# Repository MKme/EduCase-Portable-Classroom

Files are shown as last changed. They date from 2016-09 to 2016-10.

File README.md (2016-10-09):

The EduCase is a fully functional classroom inside a portable case. 
It contains fully functional computers (Raspberry Pi) loaded with content, tuorials, tools 
and information which educators can use in any area of the world. 

<p align="center">
  
</p>

<p align="center">
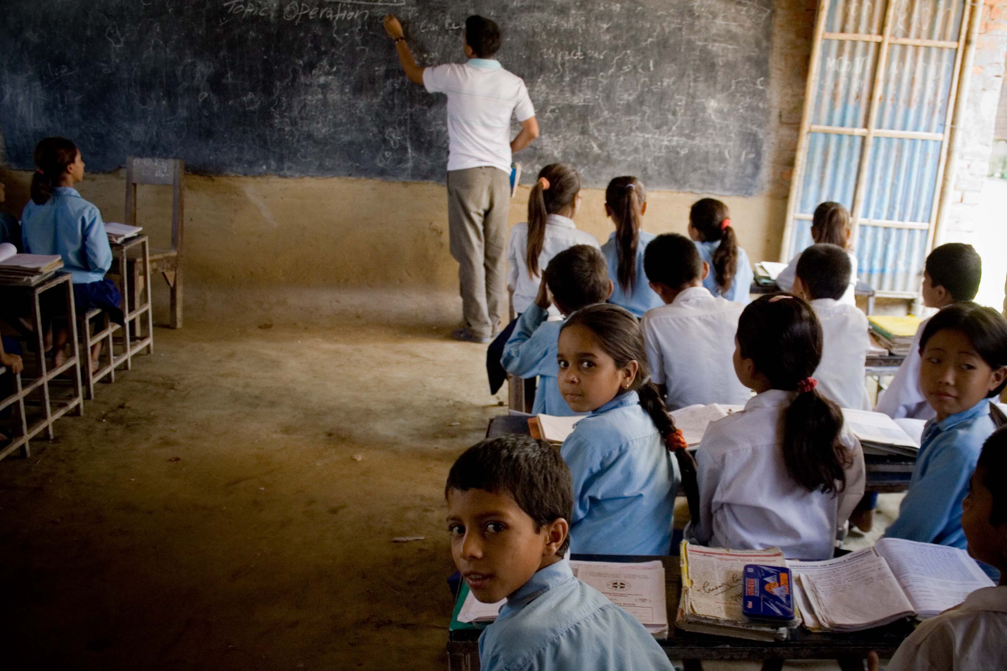
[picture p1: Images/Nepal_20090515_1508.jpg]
  
</p>
The project is fully self contained and self-powered and also includes provisions for communication 
with the outside world using either cellular data or a dedicated portable satellite dish and receiver 
linked to the Outernet. 

The case houses it's own LCD display but also utilizes an LED projector enabling the entire 
classroom to take part in any content.

<p align="center">
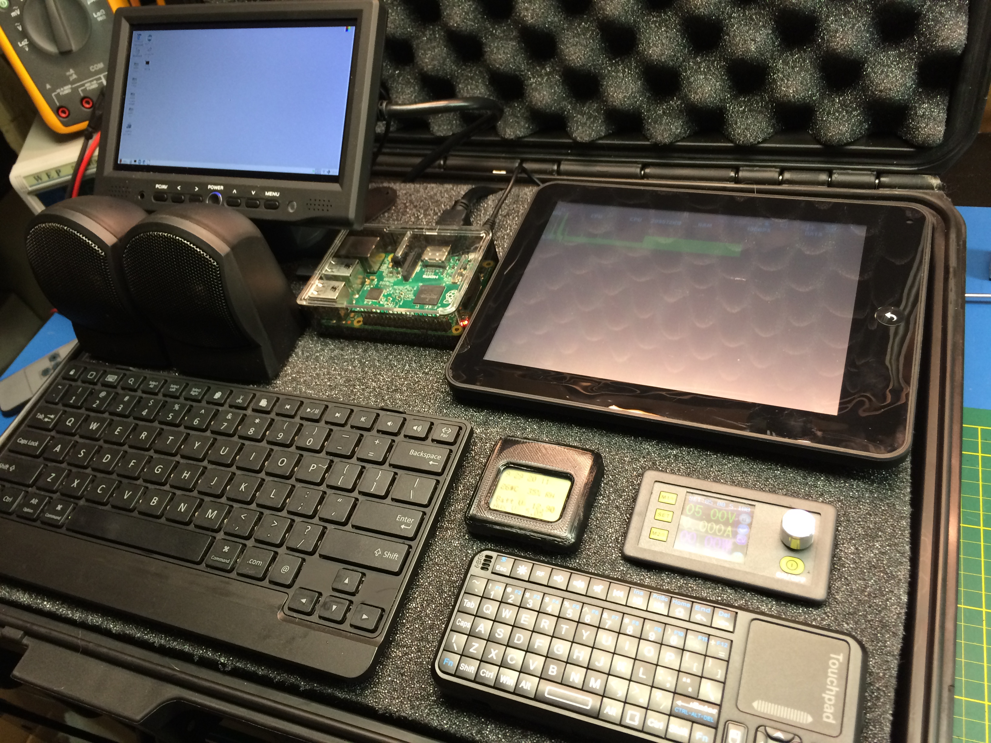
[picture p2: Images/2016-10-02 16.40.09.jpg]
  
</p>

Internal monitoring and control now provided via an Arduino Running the Aurora V1.2 Firmware. This code is 
Fully open-source and free for all to use and modify.
<p align="center">
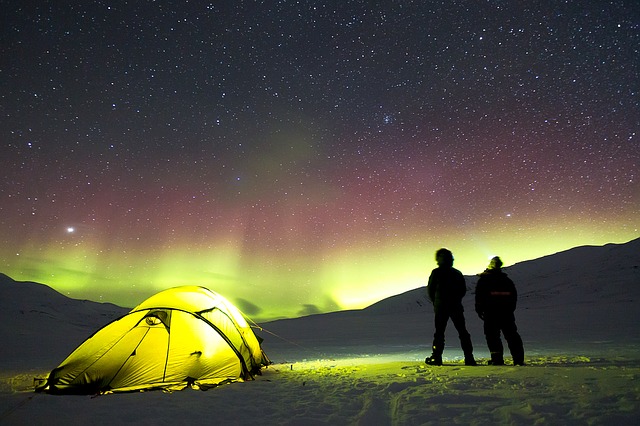
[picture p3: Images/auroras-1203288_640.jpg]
  
</p>

Project documented on Hackaday Here:
https://hackaday.io/project/11010-educase-portable-classroom

<p align="center">
  
</p>

See more of our open source projects at http://www.mkme.org  We try to share as many projects as possible which might someday
make the world a better place.

Cheers
Eric

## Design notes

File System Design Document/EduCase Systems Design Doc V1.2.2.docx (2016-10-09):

# System Design Document

# V1.2.2

Overview

The EduCase is a fully functional classroom inside a portable case. It contains multiple computers (Raspberry Pi & Android) loaded with content, tutorials, tools and information which educators can use in any area of the world.

The project is fully self-contained and self-powered and also includes provisions for communication with the outside world using either cellular data or a dedicated portable satellite dish and receiver linked to the "Outernet" satellite data provider. It also houses it's own LCD display and utilizes an LED projector enabling the entire classroom to see the content.

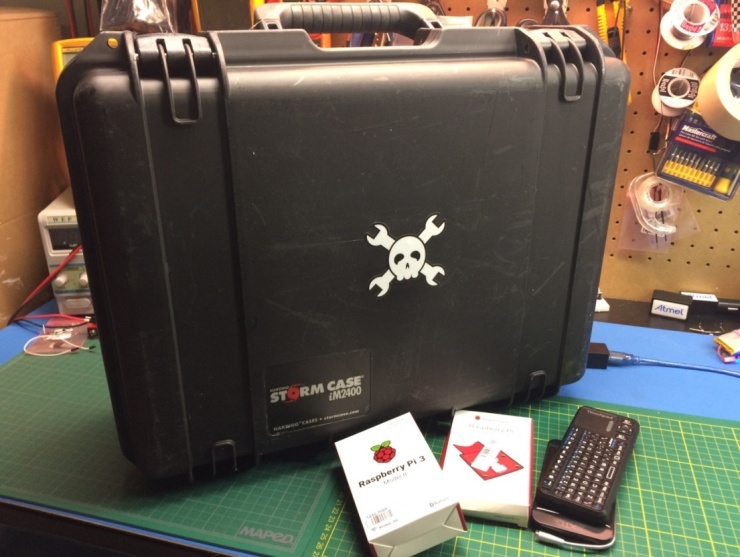
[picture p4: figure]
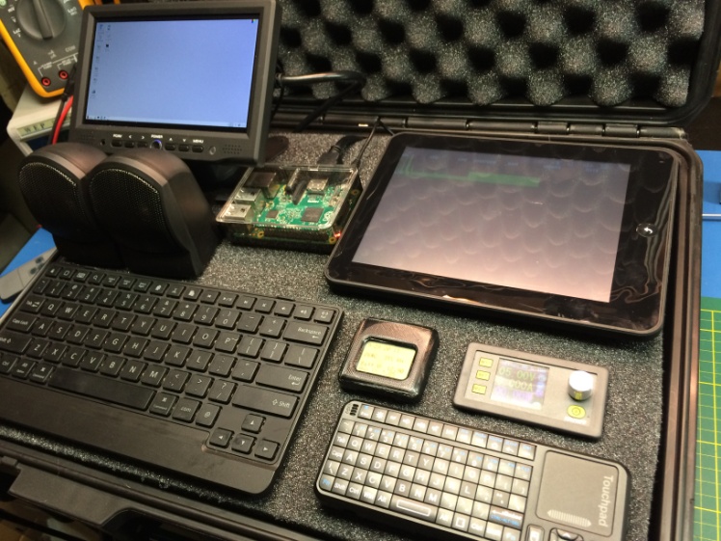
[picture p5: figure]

The EduCase can be deployed to refugee camps, rural areas, developing nations or anywhere else around the world and used to provide content, communications, courses and material we take for granted in the western world.

The EduCase can also be deployed into disaster/relief zones and used for sharing news, communication or things as simple as an impromptu movie theater.

# 1 INTRODUCTION

## 1.1 Purpose and Scope

This document is a work in progress and will be updated OFTEN. Thanks for your understanding!

The EduCase will be able to deploy technical training, medical knowledge, communication, news, and contentfrom all fields into any area of the world regardless of infrastructure.

## 1.2 Project Executive Summary

The project is open to all user modification and improvements. At its core the Raspberry Pi computer(s) provide the content and computer power needed to share information via the on board screen and projector.

This can be extremely useful for aid workers, teachers, refugee camp employees and many more.

### 1.2.1 System Overview

The Raspberry Pi computers are used to store the information, lessons and content. This can interface with the optional "Outernet" satellite downlink system or via cellualr data by tethering to the Android phone.

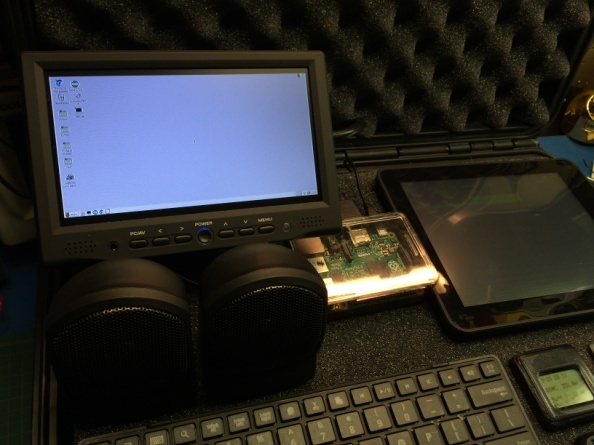
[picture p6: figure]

On board batteries supply power which can be replenished via mains power, solar panel, automotive power, generator or any other suitable source.

On board LCD display can be used for single users or deploy the included LED projector for displaying on any flat surface in order to share with a group.

Parts Video:

https://youtu.be/J0L335KiNEU

### 1.2.2 Design Constraints

Space in the case is limited so care had to be taken to include as many peripherals as possible without exceeding the volume available.

On board battery supply is limited to conserve weight but can easily be expanded if the situation requires. Lead acid batteries can also be substituted for LiPo units to reduce weight by capacity ratio.

Rasbian Image License: Debian Free Software Guidelines (https://en.wikipedia.org/wiki/Debian_Free_Software_Guidelines) (DFSG)

### 1.2.3 Future Contingencies

Expansion to control systems may require further modification. This document and files will be updated via GitHub to retain version control.

## 1.3 Document Organization

Basic explanations with expansion into subsystems as necessary.

## 1.4 Points of Contact

Support provided via the forum at http://mkme.org as well as the GIT repository.

https://github.com/MKme/EduCase-Portable-Classroom

Support for the libraries used to support the code is provided by the original authors only. Restrictions for use can be found on their respective support pages (linked within the Arduino Source Code and Raspberry Pi Files)

Forum Thread:

http://mkme.org/forum/viewtopic.php?f=32&t=702

## 1.5 Project References

Initial design completed spring 2016. Testing and updates ongoing via Hackaday website:

https://hackaday.io/project/11010-educase-portable-classroom

## 1.6 Glossary

Arduino-Arduino is an open-source computer hardware and software company, project and user community that designs and manufactures microcontroller-based kits for building digital devices and interactive objects that can sense and control the physical world.

The project is based on a family of microcontroller board designs manufactured primarily by SmartProjects in Italy, and also by several other vendors, using various 8-bit Atmel AVR microcontrollers or 32-bit Atmel ARM processors. These systems provide sets of digital and analog I/O pins that can be interfaced to various expansion boards ("shields") and other circuits. The boards feature serial communications interfaces, including USB on some models, for loading programs from personal computers. For programming the microcontrollers, the Arduino platform provides an integrated development environment (IDE) based on the Processing project, which includes support for C,C++ and Java programming languages.

# 1 SYSTEM ARCHITECTURE

Raspberry Pi Rasbian image provides basic operating system

## 1.1 Control System Architecture (Aurora Firmware)

For control and monitoring of the battery system there is an optional microcontroller control and supervision module. This consists of the Arduino Nano, temperature sensor, Real Time Clock and voltage monitoring.

The firmware (Arduino code) running on the controller is now merged into Aurora and found on GitHub

Aurora V1.2

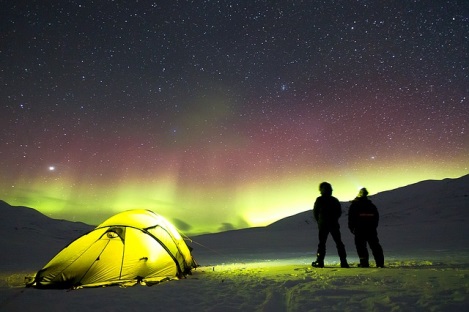
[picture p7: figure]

## 1.2 Internal Communications Architecture

Raspberry Pi wifi can be tethered to either the Lighthouse wifi hotspot or to the cellular network via the Android phone

# 2 FILE AND DATABASE DESIGN

All files and updates via GitHub:

https://github.com/MKme/EduCase-Portable-Classroom

## 2.1 System Files

- Raspberry Pi running the Raspbian operating system. Android phone and MK809 running Android OS with automatic updates.

## 2.2 Non- System Files

- Remote updates and file downloads from the Outernet interface as well as standard data delivery over cellular data.

# 3 HUMAN-MACHINE INTERFACE

1. LCD Monitor
2. LED Pico Projector
3. Android Phone Display
4. Battery Monitoring Display (Nokia 5110 LCD)

## 3.1 Inputs

- Wireless Keyboard
- Bluethooth Keyboard
- Wireless Mouse
- Touch pads on Tablet PC & Cellular Phone

## 3.2 Outputs

- HDMI video
- Stereo Audio
- Wireless LAN
- Bluetooth Data

# 4 DETAILED DESIGN

## 4.1 High Level Schematic Diagram

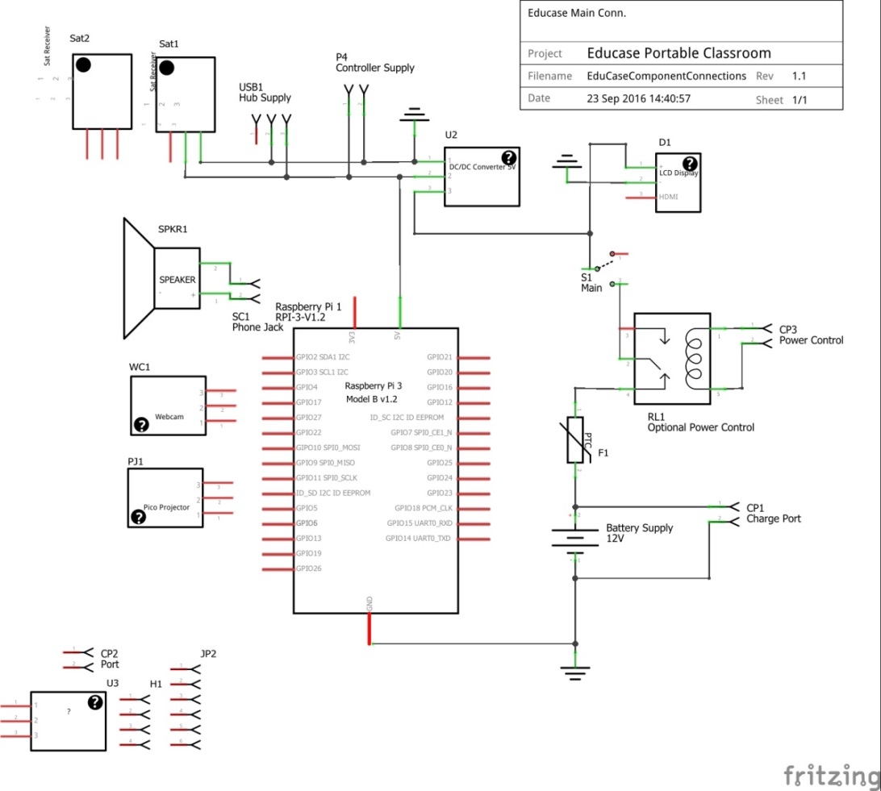
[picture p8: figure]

## 4.2 Software Detailed Design

Software design for all programs used is beyond the scope of this document. Software logic for the monitoring and control systems can be summarized in the blow functional flow.

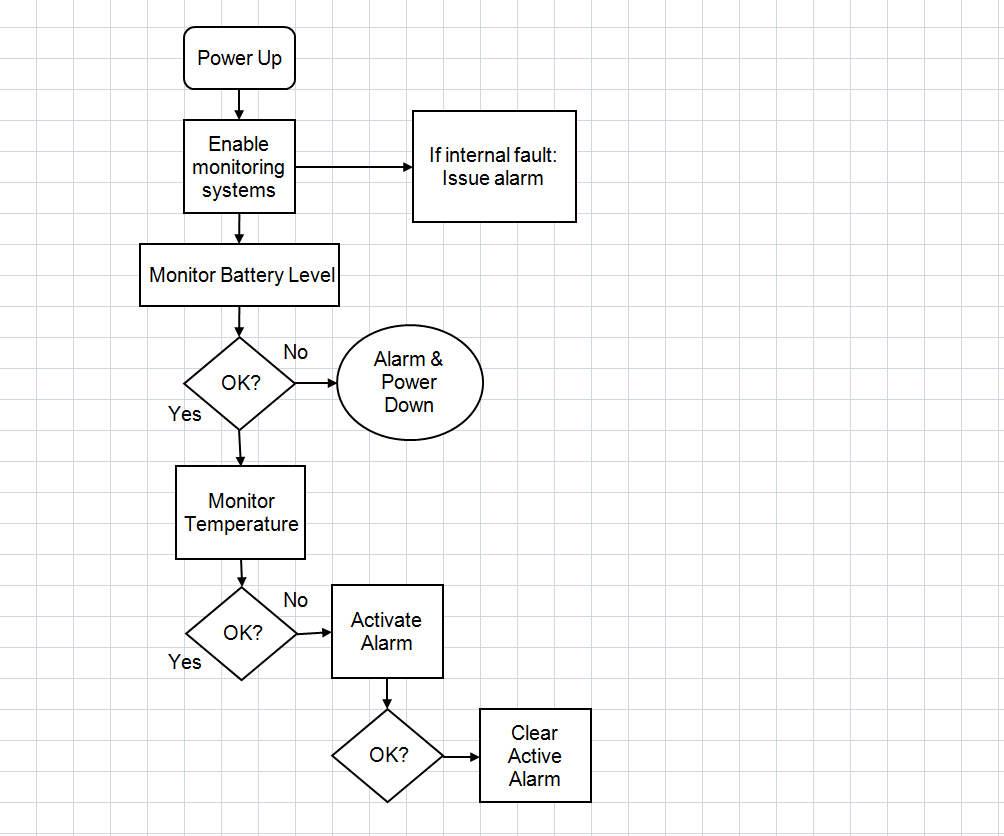
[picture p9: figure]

Functional description of the control logic:

Alarm indications are provided to the user via the LCD display. The backlight for the display flashes at 1hz while AlarmActive==True. Future models will incorporate audible notification as well.

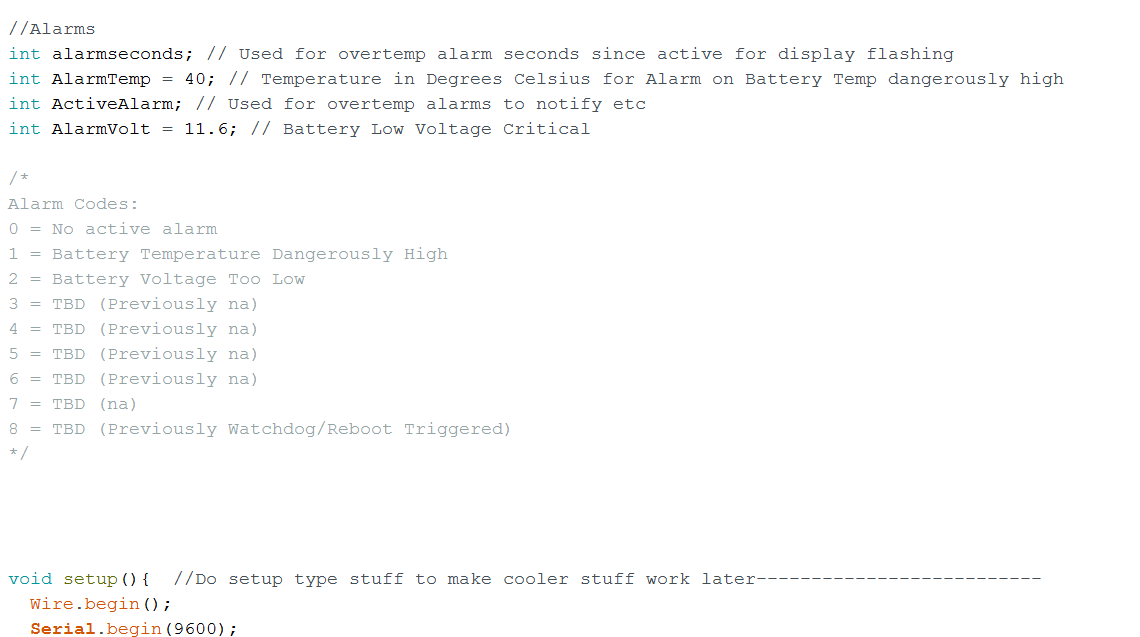
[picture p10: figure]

Much of the details can be found in the Arduino code itself (Aurora V1.2)

Example Alarm Info:

## 4.3 Internal Communications Detailed Design

- Wireless networking via 2.4 ghz utilized for file transfer between systems
- I2C communication utilized for Real Time Clock
- SPI utilized for remaining components

# 5 EXTERNAL INTERFACES

- Cellular Mobile data
- Outernet satellite receiver system

## 5.1 Control Board Design

Full Gerber files provided via GitHub Repository. These files are provided open source to anyone. These files will be updated in the upcoming months to include better trace routing and provisions for more dedicated ports (buzzer, etc)

Top:

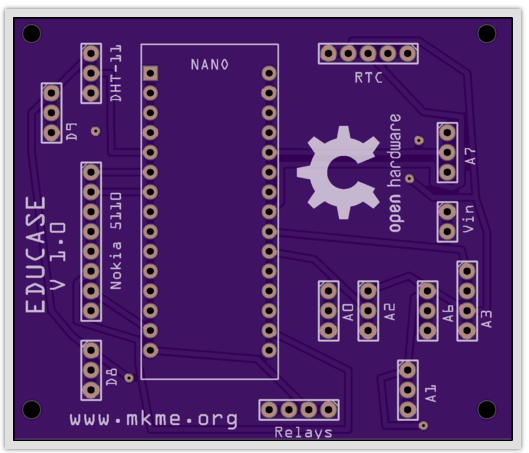
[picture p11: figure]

Bottom:

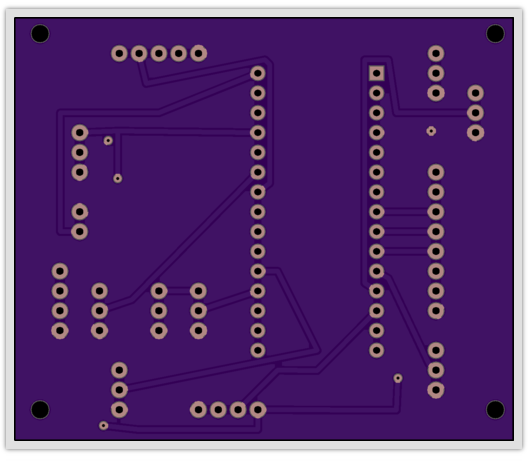
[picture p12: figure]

Educase portable classroom www.mkme.org

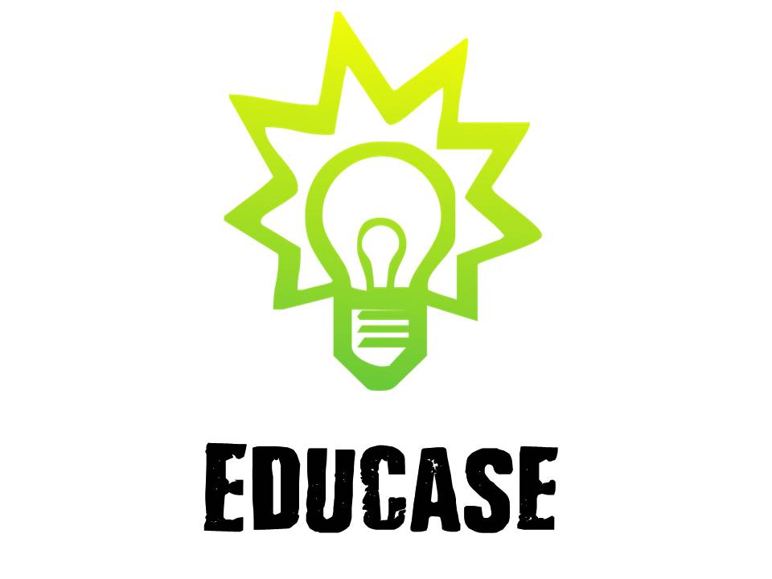
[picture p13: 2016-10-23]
Images/EduCase Pi Wallpaper.jpg

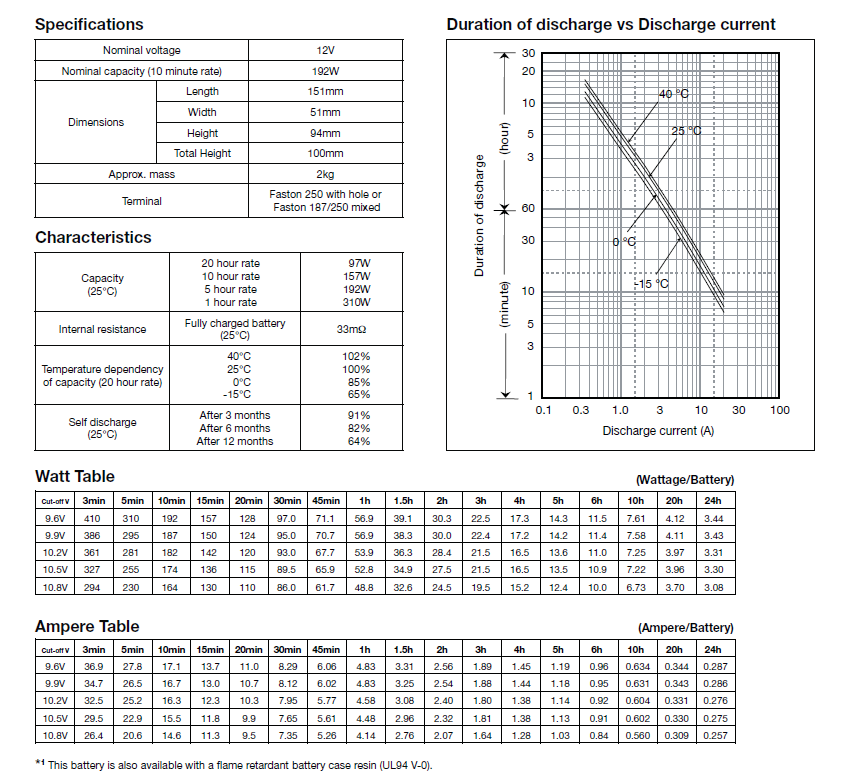
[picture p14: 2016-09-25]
Images/BatterySpecs.PNG

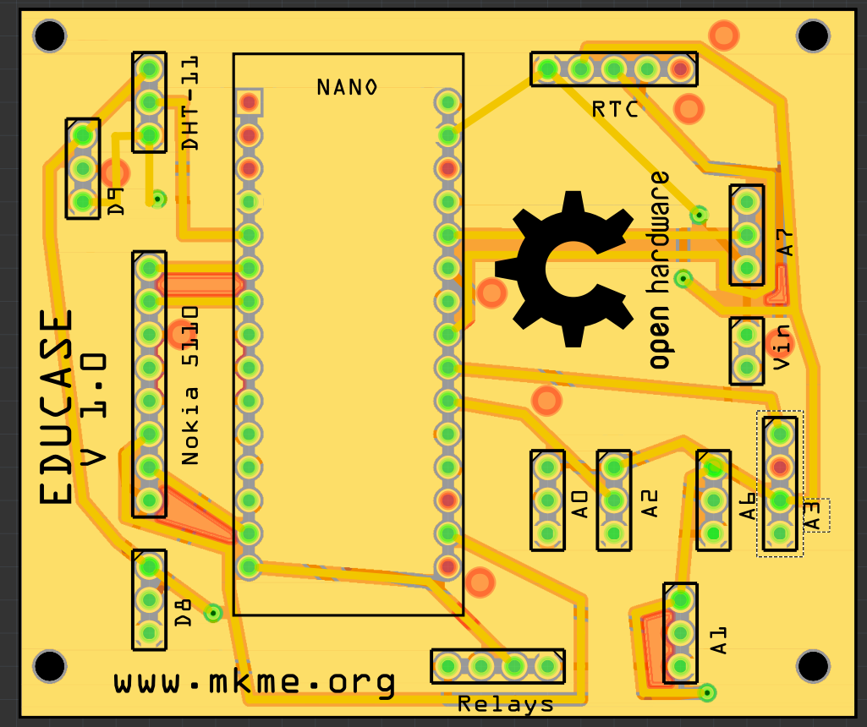
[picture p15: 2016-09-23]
Controller PCB and Schematics/Board Layout .PNG

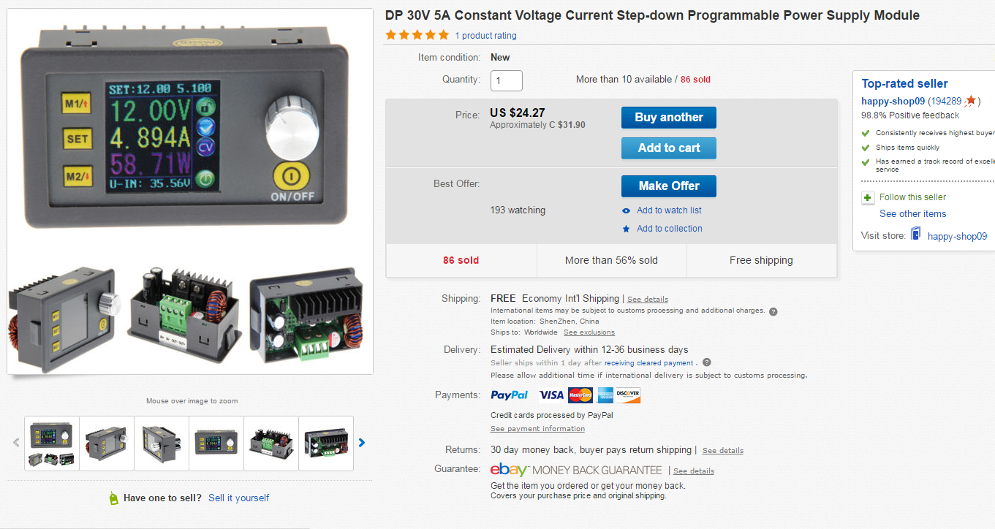
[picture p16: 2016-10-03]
Images/ElectyronicsLab Power Supply.PNG

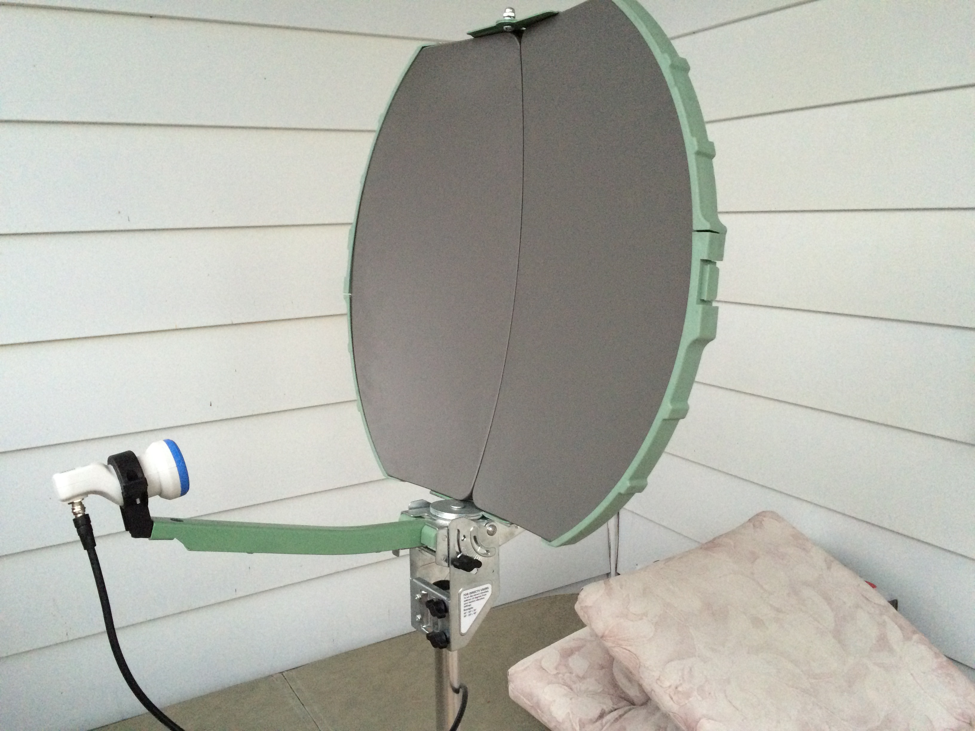
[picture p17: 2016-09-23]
Images/2015-12-30 16.21.28-1.jpg

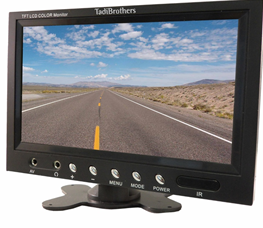
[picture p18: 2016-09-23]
Images/monitor.PNG

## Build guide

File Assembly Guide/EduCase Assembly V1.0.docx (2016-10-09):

# V1.0- Initial commit

# V1.1- Updated Parts/Links

# V1.1- Complete overhaul

Assembly Guide Overview

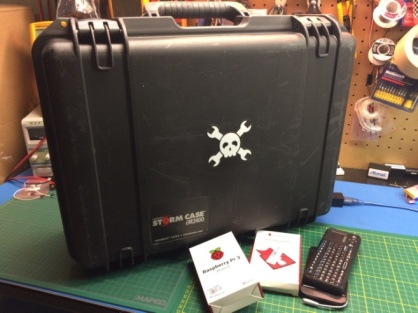
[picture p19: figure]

The EduCase is a fully functional classroom inside a portable case. It contains multiple computers (Raspberry Pi & Android) loaded with content, tutorials, tools and information which educators can use in any area of the world.

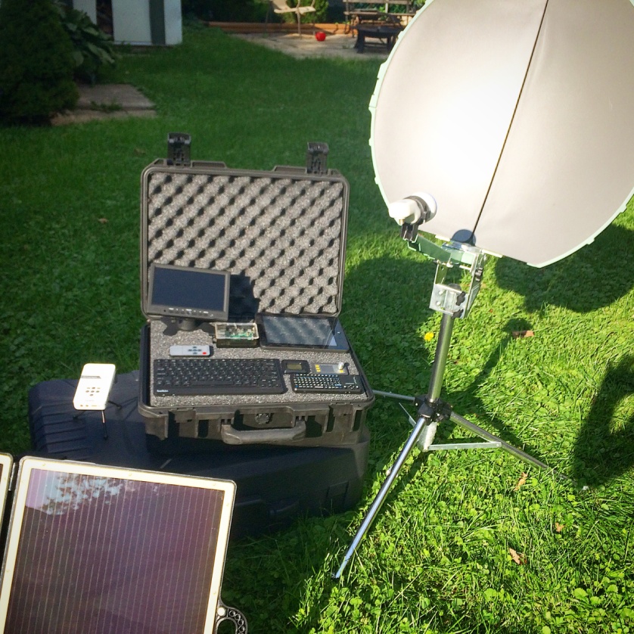
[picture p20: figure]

The project is fully self-contained and self-powered and also includes provisions for communication with the outside world using either cellular data or a dedicated portable satellite dish and receiver linked to the "Outernet" satellite data provider.

It also houses its own LCD display and utilizes an LED projector enabling the entire classroom to see the content.

The EduCase can be deployed to refugee camps, rural areas, developing nations or anywhere else around the world and used to provide content, communications, courses and material we take for granted in the western world.

The EduCase can also be deployed into disaster/relief zones and used for sharing news, communication or things as simple as an impromptu movie theater.

# 1 INTRODUCTION

## 1.1 Basics

This document is a work in progress and will be updated OFTEN. Thanks for your understanding!

The EduCase will be able to deploy technical training, medical knowledge, communication, news, and contentfrom all fields into any area of the world regardless of infrastructure.

## 1.2 References

Parts Video: https://youtu.be/J0L335KiNEU

Contact

Support provided via the forum at http://mkme.org as well as the GIT repository.

Support for the libraries used to support the code is provided by the original authors only. Restrictions for use can be found on their respective support pages (linked within the Arduino Source Code and Raspberry Pi Files)

Forum Thread:

http://mkme.org/forum/viewtopic.php?f=32&t=702

# All files and source code:

All files and updates via GitHub:

https://github.com/MKme/EduCase-Portable-Classroom

## 1.3 Project References

Initial design completed spring 2016. Testing and updates ongoing via Hackaday website:

https://hackaday.io/project/11010-educase-portable-classroom

## 1.4 Assembly

1. Gather the required components for assembly into your case. Pelican style cases are preferred due to the depth and resistance to water intrusion. You can find many options here: http://www.pelicancases.com/

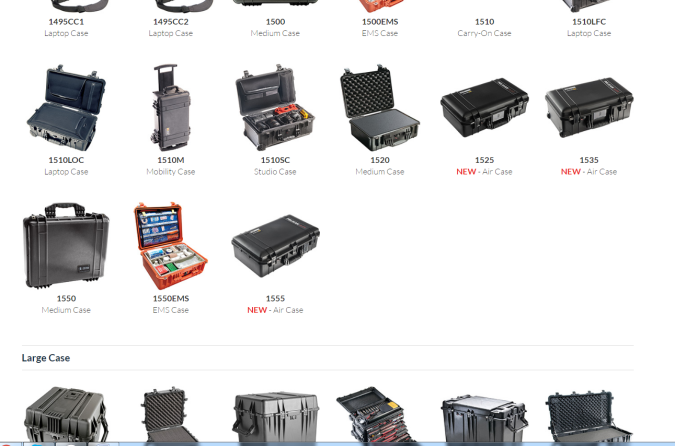
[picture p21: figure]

I made a sort parts overview video you can see here: https://www.youtube.com/watch?v=J0L335KiNEU

2. Assemble the batteries into the case as per the electrical schematic found on GitHub.

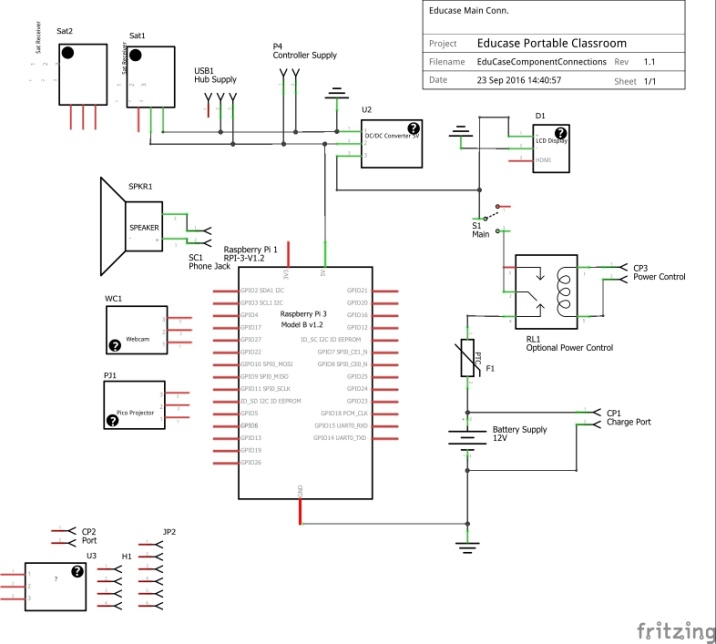
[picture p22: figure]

You can use any time of battery you wish but it is preferable to use lead acid batteries which lend themselves better to these discharge cycles better than LiPo etc.

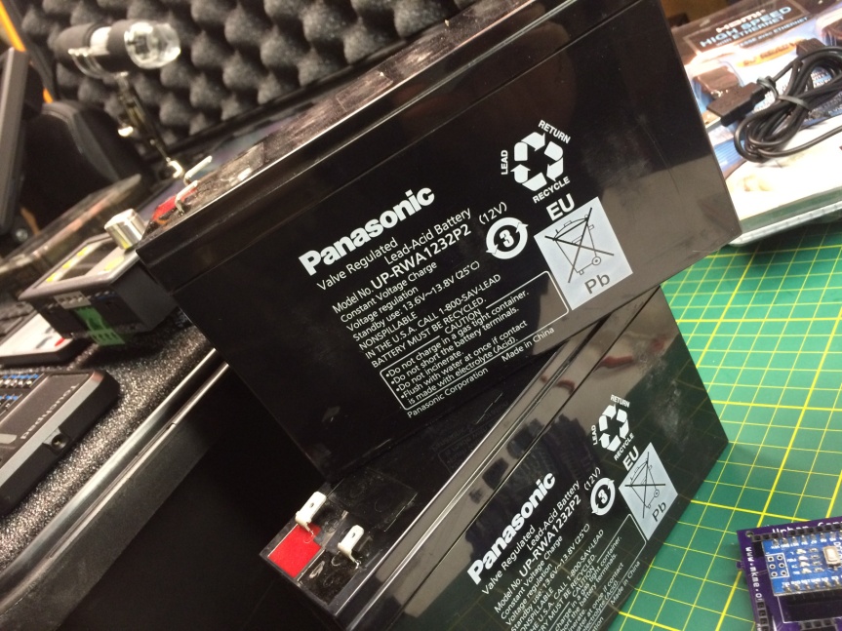
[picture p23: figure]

Ensure you fuse the battery output as per the schematic using protection of your choice. A PTC is preferable but and automotive spade-style fuse can also be used and are easily available from many sources

3. At this time it is best to decide if you will incorporate the Arduino controller into the case.

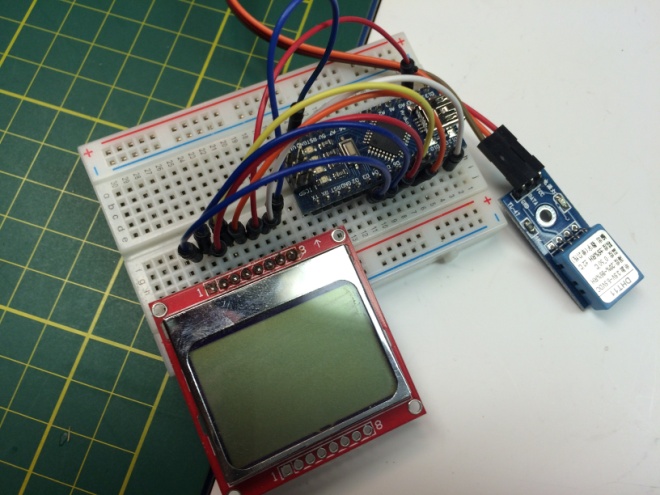
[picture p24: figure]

It will be easier to wire the relay power control and temperature sensor now before you finalize the component locations inside the case. If you choose to use the control you can order the printed circuit board using the files I have provided on GitHub. Wire the components as per the layout in the code and schematics and flash the Arduino with the code provided.

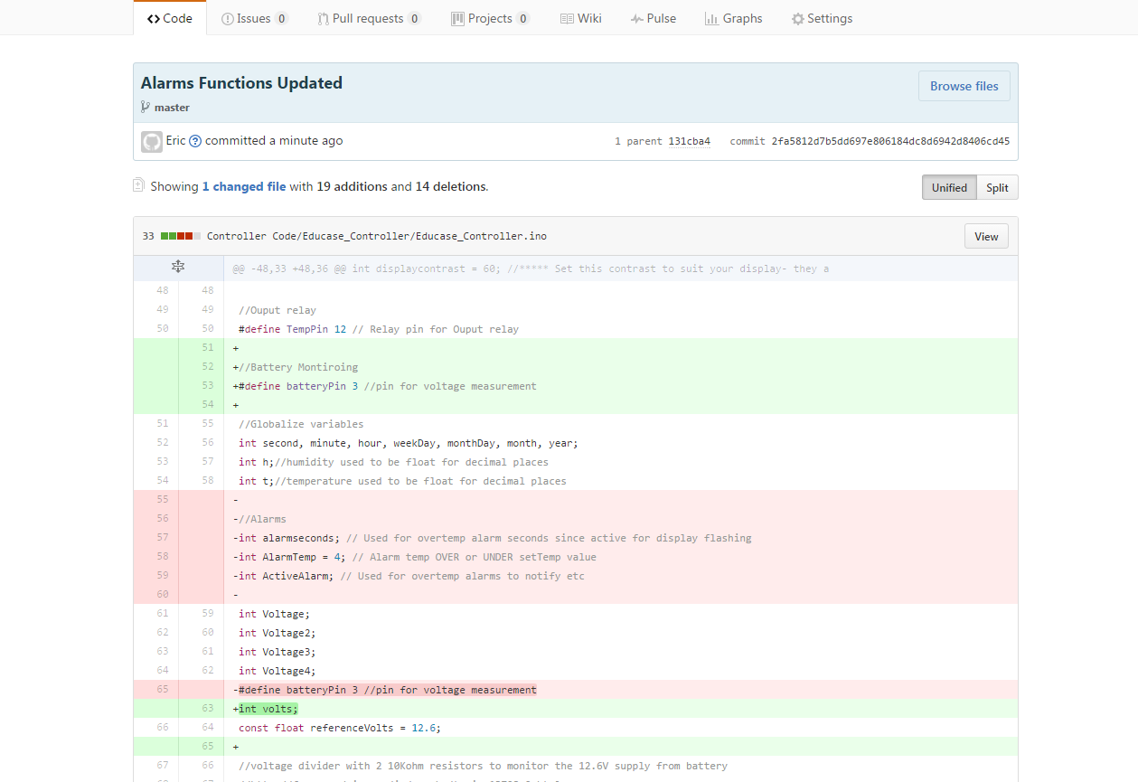
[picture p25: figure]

Download the Aurora firmware from Github and flash using the Arduino IDE from https://www.arduino.cc/en/Main/Software

4. If you implement the controller you may wish to mount your Nokia 5110 LCD permanently in the case. Within the files on Github there is a folder for CAD files and documents. Within it you will find a stylish bezel for the LCD. You can 3D print this yourself or use and online source such as Shapeways.

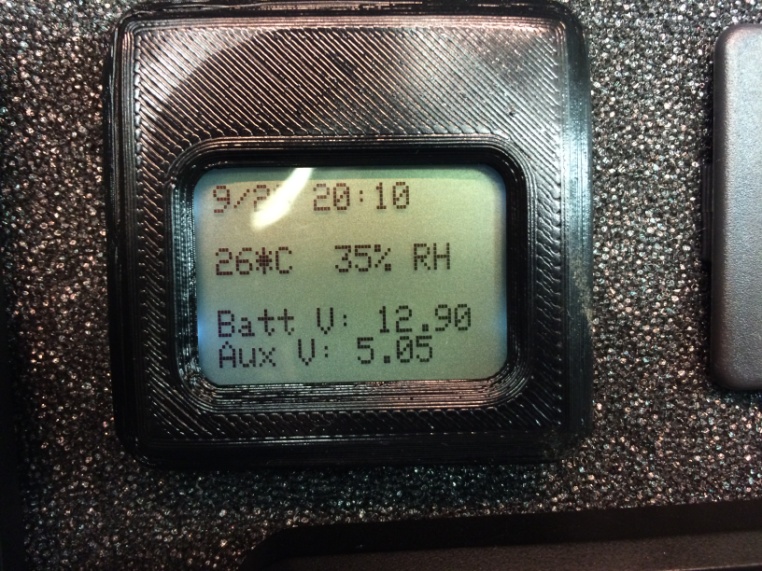
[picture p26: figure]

5. Customize the code as you wish to include time, temperature and voltage alarms and control. If you make changes please consider sharing them back with the world open-source.


6. Lay out the components inside your case as per your hardware. You can use the foam inserts and carve them out to snugly fit your monitor, Raspberry Pi and still leave room for storage of components and equipment such as webcams, remotes etc

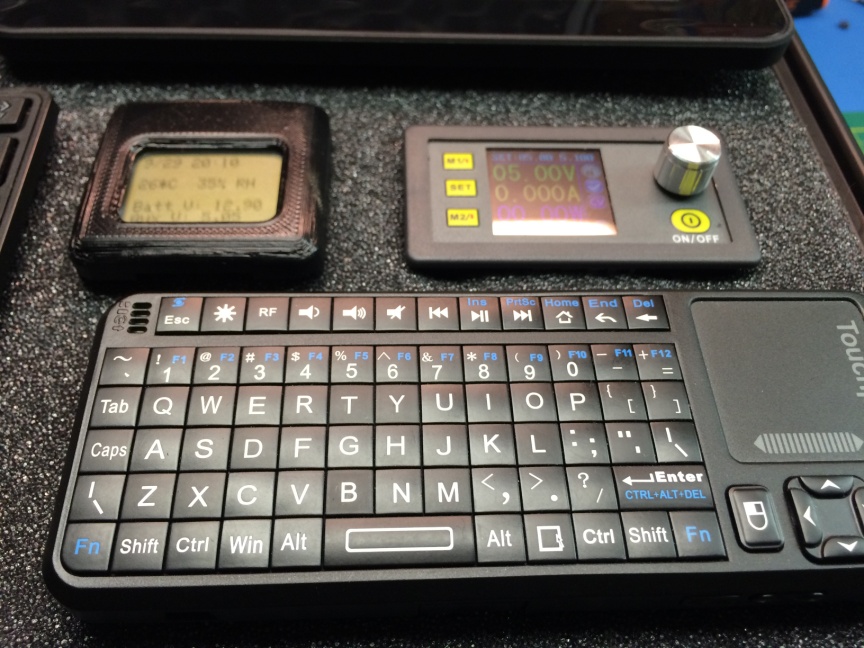
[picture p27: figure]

Route the USB wiring, video and audio cables to suit your installation. I suggest leaving extra HDMI cable easily accessible so the projector and monitor can be used outside the case. This makes presenting to a classroom environment much easier as you can place the case away from your work/presentation area.

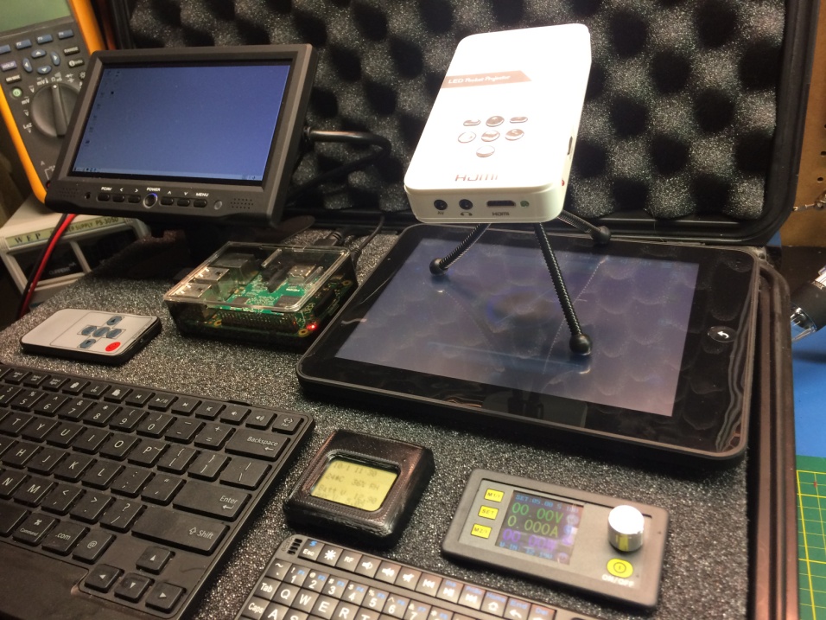
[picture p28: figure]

7. Add a powered USB hub with the number of ports needed for your particular project. I suggest at least 10. The power for the hub is supplied via the DC/DC converter as per the schematic.

These units can be found as “buck converters” from any electronics source. Some suggested versions are given in the parts list in this project.

Mount the hub so it is convenient to access at least a few ports during normal use for plugging in items for charging, webcams etc.

8. Install the Raspbian operating system on your Raspberry Pi. I have made a video detailing this here:https://www.youtube.com/watch?v=29ejr-KFxvY

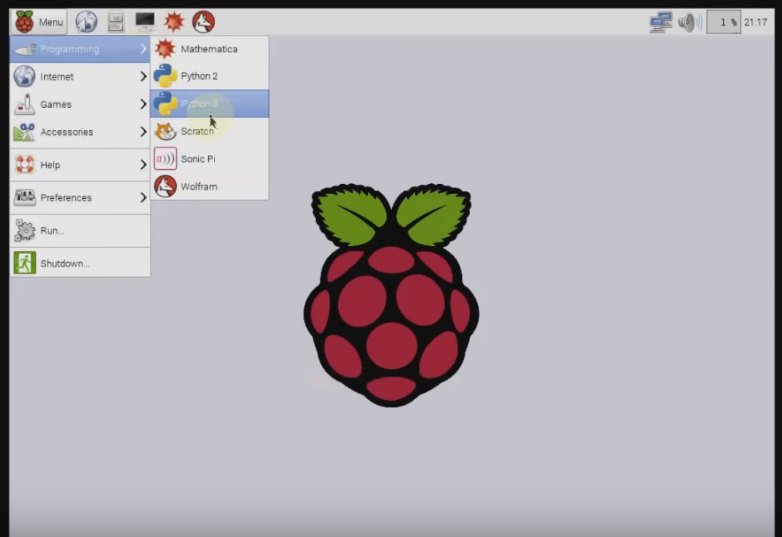
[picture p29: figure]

9. You will want to be installing many files and learning content on the Pi so installing a remote VNC connection will make this much easier. Install remote desktop connection as per the video I made here:

https://www.youtube.com/watch?v=P5lPmXTgwu0

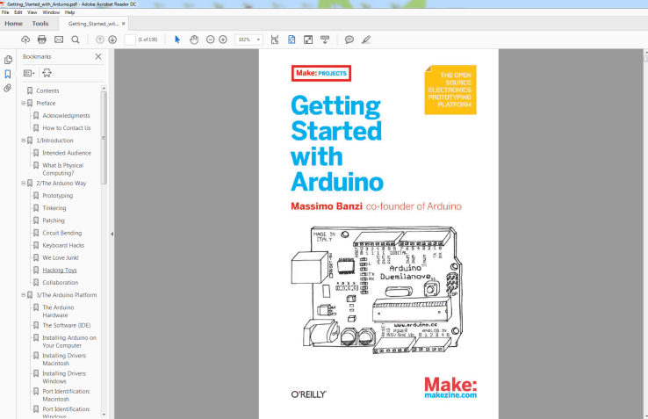
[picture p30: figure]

10. Copy all the files and content over to your Raspberry Pi. I also place some of the media files on the Android phone. It hooked up to the projector does a much better job at media file playback such as video/movies. I cannot provide the files I am using due to copyright etc so please don’t ask for them. Sorry.
11. If you are also constructing the portable satellite dish you will need to swap out the LNB that comes with the dish to a Linear LNB. They can be sourced easily on eBay or Amazon. Install the LNB in the same position as the original. The distance from the face of the LNB to the dish itself must remain the exact same to retain the correct focus.This can be done with a simple measuring tape.

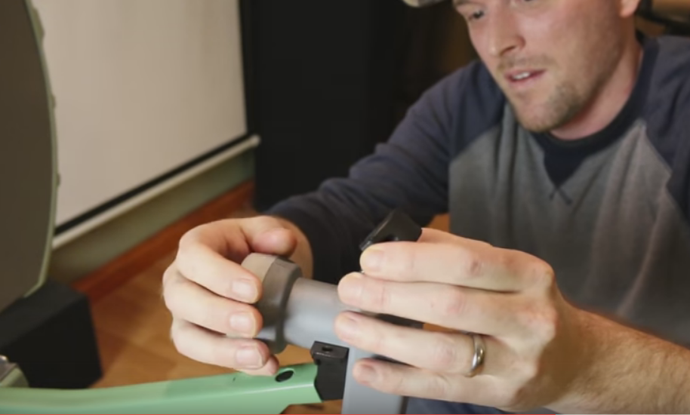
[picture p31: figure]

## 1.5 Glossary

Arduino- Arduino is an open-source computer hardware and software company, project and user community that designs and manufactures microcontroller-based kits for building digital devices and interactive objects that can sense and control the physical world.

The project is based on a family of microcontroller board designs manufactured primarily by SmartProjects in Italy, and also by several other vendors, using various 8-bit Atmel AVR microcontrollers or 32-bit Atmel ARM processors. These systems provide sets of digital and analog I/O pins that can be interfaced to various expansion boards ("shields") and other circuits. The boards feature serial communications interfaces, including USB on some models, for loading programs from personal computers. For programming the microcontrollers, the Arduino platform provides an integrated development environment (IDE) based on the Processing project, which includes support for C,C++ and Java programming languages.

Educase portable classroom- Assembly Guide www.mkme.org

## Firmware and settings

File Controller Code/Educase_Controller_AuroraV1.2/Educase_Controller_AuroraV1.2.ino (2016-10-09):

/* 
Erics Open Source Educase Portable classroom
Firmware: Aurora V1.2

This code is for the Arduino monitoring and control board to prevent damage to onboard systems
Alarms displayed via LCD and power control via relay RL1
My Youtube Channel  : http://www.youtube.com/mkmeorg
If you use this code or personalize it etc- please consider sharing it back with the world Open-Source 
This sketch is currently using Arduino Nano V3.0

Get all schematics and instructions for the EduCase project on GitUHub at https://github.com/MKme/EduCase-Portable-Classroom

This code uses the fantastic Nokia 5110 library provided FREE by Adafruit Industries
If you use this for your project consider buying some of your parts from them at http://adafruit.com
Show them some love for supporting the maker movement with tonnes of free tutorials and code.

Real Time Clock (RTC) support:
 http://www.hobbyist.co.nz/?q=real_time_clock
 RTC Connected to VCC and Ground Only- Additional Vbatt and Temp to be added later
 I2C Connections:
 RTC SDA connected to pin Analog 4
 RTC SCL connected to pin Analog 5

Used I2CScanner.ino to find I2C addresses- 0x50 (EEPROM?)  and 0x68 found
Used SetRTC.ino to manually set proper date/date on RTC module- This wil set the date/time as soon as serial 
is initiated so set ahead by a minute and wait till time matches then open serial window to set.
Downloaded from http://projectsfromtech.blogspot.com/

DHT11 Temp Sensor:
Connect pin 1 (on the left) of the sensor to +5V
Connect pin 2 of the sensor to whatever your DHTPIN is
Connect pin 4 (on the right) of the sensor to GROUND
Connect a 10K resistor from pin 2 (data) to pin 1 (power) of the sensor

Pin 11 for contrast on the Nokia 5110 (see below)

*/

#include "Wire.h" //RTC
#define DS1307_ADDRESS 0x68 //For RTC Support
byte zero = 0x00; //workaround for issue #527 on RTC
#include "DHT.h"  //You need this library
#define DHTPIN 2     // DHT11 Humidity Pin
#define DHTTYPE DHT11   // DHT 11 
DHT dht(DHTPIN, DHTTYPE);//needed by DHT11
#include "Adafruit_GFX.h"  //Awesome Adafruit libraries- download from their site
#include "Adafruit_PCD8544.h"  //Awesome Adafruit libraries- download from their site
Adafruit_PCD8544 display = Adafruit_PCD8544(7, 6, 5, 4, 3);//4 and 3 are reversed on the cheap eBay models

//LCD display & backlight control 
#define backlightpin 11 //Pin for LCD backlight
int backlightlevel = 220; //Level for backlight PWM
int backlightoff = 255; //Level which turns backlight off completely
int displaycontrast = 60; //***** Set this contrast to suit your display- they are indeed different between production runs

//Ouput relay
#define LIGHTPIN 10 //Pin for output relay

//Temp Pin if used
#define TempPin 12 // Relay pin for Temp

//Battery Montitoring
#define batteryPin 3 //pin for voltage measurement

//Globalize variables
int second, minute, hour, weekDay, monthDay, month, year;
int h;//humidity used to be float for decimal places
int t;//temperature used to be float for decimal places
int Voltage;
int Voltage2;
int Voltage3;
int Voltage4;
int volts;
const float referenceVolts = 12.6;  

//voltage divider with 2 10Kohm resistors to monitor the 12.6V supply from battery
//http://forum.arduino.cc/index.php/topic,13728.0.html
//currently rersistors not included on pre-made PCB so wire externally

//Alarms
int alarmseconds; // Used for overtemp alarm seconds since active for display flashing
int AlarmTemp = 40; // Temperature in Degrees Celsius for Alarm on Battery Temp dangerously high
int ActiveAlarm; // Used for overtemp alarms to notify etc
int AlarmVolt = 11.6; // Battery Low Voltage Critical

/*
Alarm Codes:
0 = No active alarm
1 = Battery Temperature Dangerously High
2 = Battery Voltage Too Low
3 = TBD (Previously na)
4 = TBD (Previously na)
5 = TBD (Previously na)
6 = TBD (Previously na)
7 = TBD (Previously Fatal Error)
8 = TBD (Previously Watchdog/Reboot Triggered)
*/




void setup(){  //Do setup type stuff to make cooler stuff work later--------------------------
  Wire.begin();
  Serial.begin(9600);
  dht.begin();//initialize temp and humidity
  analogWrite(backlightpin,backlightlevel);// PWM of LCD backlight but ebay unit is backwards-   //must go high + cycle to dim   //Very Dim=230
  display.begin();//Display code
  display.setContrast(displaycontrast);//Nokia 5110 works best at 50- no more flicker
  delay(1000);  //party foul I know but it is only setup
  display.clearDisplay();     // clears the screen and buffer- makes gooder stuff show up later
  display.setTextSize(1);     // set text size
  display.setTextColor(BLACK);
  
 // Splash Screen - 
  display.setTextSize(1);
  display.setTextColor(BLACK);
  display.setCursor(0,0);
  display.println("  Eric's");
  display.println("");
  display.println(" Educase");
  display.println(" Portable");
  display.println(" Classroom");
  display.display();
  delay(2000);
  display.clearDisplay();     // clears the screen and buffer
  
 }

void loop(){
  TimeFunctions();   //Do the time related stuff
  TempFunctions();   //Do the temp related stuff
  VoltageFunctions();   //Do the temp related stuff
  debug();           //Figure out what has broken type of stuffs
  LCDDisplay();      //Send everything to the LCD display
  Alarm();           //Activate alarm if applicable
  DisplayFlash();    //Flash display if alarm active
  
}


//------------------------------This needed by RTC
byte decToBcd(byte val){  //Needed for RTC
// Convert normal decimal numbers to binary coded decimal
  return ( (val/10*16) + (val%10) );
}

byte bcdToDec(byte val)  {  //Needed for RTC
// Convert binary coded decimal to normal decimal numbers
  return ( (val/16*10) + (val%16) );
}
//------------------------------End needed by RTC


//Do time related stuffs so cool stuffs work gooder------------------------------
void TimeFunctions(){ 
  // Reset the register pointer
  Wire.beginTransmission(DS1307_ADDRESS);
  Wire.write(zero);
  Wire.endTransmission();
  Wire.requestFrom(DS1307_ADDRESS, 7);
  second = bcdToDec(Wire.read());
  minute = bcdToDec(Wire.read());
  hour = bcdToDec(Wire.read() & 0b111111); //24 hour time
  weekDay = bcdToDec(Wire.read()); //0-6 -> sunday - Saturday
  monthDay = bcdToDec(Wire.read());
  month = bcdToDec(Wire.read());
  year = bcdToDec(Wire.read());
}

//Do temperature related stuffs----------------------------------------------------------
void TempFunctions(){
  // Reading temperature or humidity takes about 250 milliseconds!
  // Sensor readings may also be up to 2 seconds 'old' (its a very slow sensor)
  h = dht.readHumidity();
  t = dht.readTemperature();
}

void VoltageFunctions(){
int val = analogRead(batteryPin);  // read the value from the A0 battery monitoring pin with voltage divider
//if you run in to any odd measurements here- take a second read and throw out the first- this will get rid of the known analog read bug with some chips
float volts = (val / 511.0) * referenceVolts ; // divide val by (1023/2)because the resistors divide the voltage in half
  
}
//Do debugging stuffs for nerds only-----------------------------------------------------------------
void debug(){  //This area only used for debugging any changes to the code- handy dandy sometimes :)
  if (Serial.available()){ //Can leave debug active as no resources used when not connected
  //Date and Time Values   3/1/11 23:59:59
  Serial.print(month);
  Serial.print("/");
  Serial.print(monthDay);
  Serial.print("/");
  Serial.print(year);
  Serial.print(" ");
  if (hour < 10) Serial.print("0");
  Serial.print(hour);
  Serial.print(":");
  if (minute < 10) Serial.print("0");
  Serial.print(minute);
  Serial.print(":");
  if (second < 10) Serial.print("0");
  Serial.println(second);
    //humidity Sensor Values
    // check if returns are valid, if they are NaN (not a number) then something went wrong!
    if (isnan(t) || isnan(h)) {
      Serial.println("Failed to read from DHT");} 
    else {
      Serial.print("Humidity: "); 
      Serial.print(h);
      Serial.print(" %\t");
      Serial.print("Temperature: "); 
      Serial.print(t);
      Serial.println(" *C"); }

//Alarm Status
  Serial.print("Active Alarm "); 
  Serial.println(ActiveAlarm);
}}

//Write everything to the LCD so folks can see what's up---------------------------------
void LCDDisplay(){
  display.clearDisplay();              // clears the screen and buffer
  display.setCursor(0,0);
  display.setTextSize(1);     // set text size
  display.print(month);
  display.print("/");
  display.print(monthDay);
  //display.print("/");
  //display.print(year);
  display.print(" ");
  if (hour < 10) display.print("0");
  display.print(hour);
  display.print(":");
  if (minute < 10) display.print("0");
  display.println(minute);
  //display.print(":");
  //if (second < 10) display.print("0");
  //display.println(second);
  display.println("");
  display.print(t);
  display.print("*C  ");
  display.print(h);
  display.println("% RH");
  display.print("Batt V: ");
  display.println(Voltage);
  display.print("Aux V: ");
  display.println(Voltage2);
  display.display();
  }
   
void Alarm(){
  //Overtemp  alarm--------------------------------------
  if (t >= AlarmTemp && second != alarmseconds  ) {ActiveAlarm = 1;} //Checks over or under alarm limit and setas alarm #1
  else   ActiveAlarm = 0; //No active alarm criteria met
  
  //Low Voltage Alarm
  if (volts <= AlarmVolt && second != alarmseconds  ) {ActiveAlarm = 2;} //Checks over or under alarm limit and sets alarm #2
  else   ActiveAlarm = 0; //No active alarm criteria met
  
  //Insert Alarm here
  
  //Insert non desired output alarms here
  
  //Insert SkyNet has teaken over the world via my Educase alarm here

}

//Flash the display if any alarm is active------------------------------
void DisplayFlash(){
  if (ActiveAlarm >0  && second != alarmseconds){
  alarmseconds = second; 
  analogWrite(backlightpin,backlightoff);// Turn off backlight so flashing can begin
  }
  //Else Normal backlight- no more flashing
  else 
  analogWrite(backlightpin,backlightlevel);// Normal PWM of LCD backlight
  }

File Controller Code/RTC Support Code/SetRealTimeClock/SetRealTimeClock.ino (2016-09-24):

/* Downloaded from http://projectsfromtech.blogspot.com/
*Connect SCL, SDA, Vcc, and GND
*Set date in function below.
*Upload and enjoy!
*/


//Arduino 1.0+ Only

#include "Wire.h"

#define DS1307_ADDRESS 0x68
byte zero = 0x00; //workaround for issue #527

void setup(){
  Wire.begin();
  

  
  Serial.begin(9600);
  setDateTime(); //MUST CONFIGURE IN FUNCTION
}

void loop(){
  printDate();
  delay(1000);
}

void setDateTime(){

  byte second =      0; //0-59
  byte minute =      20; //0-59
  byte hour =        17; //0-23
  byte weekDay =     6; //1-7
  byte monthDay =    24; //1-31
  byte month =       9; //1-12
  byte year  =       16; //0-99

  Wire.beginTransmission(DS1307_ADDRESS);
  Wire.write(zero); //stop Oscillator

  Wire.write(decToBcd(second));
  Wire.write(decToBcd(minute));
  Wire.write(decToBcd(hour));
  Wire.write(decToBcd(weekDay));
  Wire.write(decToBcd(monthDay));
  Wire.write(decToBcd(month));
  Wire.write(decToBcd(year));

  Wire.write(zero); //start 

  Wire.endTransmission();

}

byte decToBcd(byte val){
// Convert normal decimal numbers to binary coded decimal
  return ( (val/10*16) + (val%10) );
}

byte bcdToDec(byte val)  {
// Convert binary coded decimal to normal decimal numbers
  return ( (val/16*10) + (val%16) );
}

void printDate(){

  // Reset the register pointer
  Wire.beginTransmission(DS1307_ADDRESS);
  Wire.write(zero);
  Wire.endTransmission();

  Wire.requestFrom(DS1307_ADDRESS, 7);

  int second = bcdToDec(Wire.read());
  int minute = bcdToDec(Wire.read());
  int hour = bcdToDec(Wire.read() & 0b111111); //24 hour time
  int weekDay = bcdToDec(Wire.read()); //0-6 -> sunday - Saturday
  int monthDay = bcdToDec(Wire.read());
  int month = bcdToDec(Wire.read());
  int year = bcdToDec(Wire.read());

  //print the date EG   3/1/11 23:59:59
  Serial.print(month);
  Serial.print("/");
  Serial.print(monthDay);
  Serial.print("/");
  Serial.print(year);
  Serial.print(" ");
  Serial.print(hour);
  Serial.print(":");
  Serial.print(minute);
  Serial.print(":");
  Serial.println(second);

}

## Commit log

2016-04-13 Cad File Updates
2016-09-23 Assembly Info Updated
2016-09-23 Assembly update
2016-09-23 Updated Schematics
    [EduCaseComponentConnections.fzz]
2016-09-23 Board updates
    [EduCaseComponentConnections.fzz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]
2016-09-23 Board changes
2016-09-23 Added Missing Fuse
    [EduCaseComponentConnections.fzz]
2016-09-24 Controller Code Updated RTC
    [EduCaseComponentConnections.fzz]
2016-09-24 Updated Controller Functional Descritpion
    [EduCase Controller Functional Description.xls]
2016-09-25 Schematics Updates
    [EduCaseComponentConnections.fzz]
2016-09-25 Updated PCBs
2016-09-25 Minor Updates
    [Educase Controller.fzz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]
2016-09-26 Assembly Guide Updates
2016-09-26 Updated Assembly Guide
2016-09-27 Assembly Guide Updated
2016-10-02 Controller Functional Requirements Updates
    [EduCase Controller Functional Description.xls]
2016-10-09 Assembly Updates
2016-10-09 High Level Schematic Updated
2016-10-10 PCB File and Schematic Updates
